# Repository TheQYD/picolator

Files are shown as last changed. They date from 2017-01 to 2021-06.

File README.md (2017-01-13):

## Picolator
A portable console for [Pico 8] (http://www.lexaloffle.com/pico-8.php).   

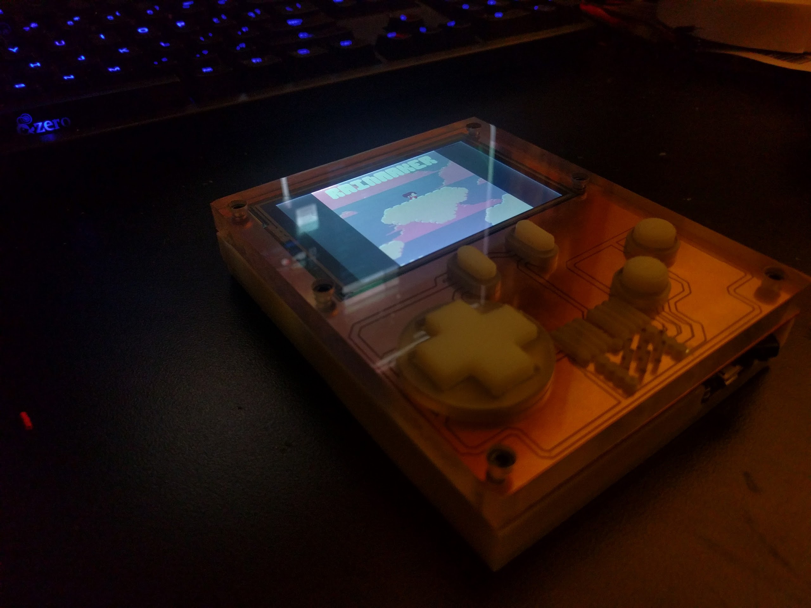
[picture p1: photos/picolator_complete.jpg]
(Picolator Complete Picolator


## Details
Picolator is a portable console developed using the Raspberry Pi Zero. It's shell and circuits are made using the [Othermill](https://othermachine.co). 

Anyone with experience in milling and circuit design should be able to make it from just the files. I'll put together an Instructable soon. Check the notes for design details.

## Parts
- 1 [Raspberry Zero] (https://www.adafruit.com/product/2885)
- 1 [Teensy 3.2] (https://www.pjrc.com/store/teensy32.html)
- 1 [Adafruit 3.5” PiTFT] (https://www.adafruit.com/products/2097)
- 1 [LM386 Audio Amplifier] (http://www.digikey.com/product-detail/en/texas-instruments/LM386N-4-NOPB/296-43960-5-ND/148192)
- 1 [Adafruit PowerBoost 500c] (https://www.adafruit.com/product/1944)
- 1 [3.7v 2500mAh LiPo battery] (https://www.adafruit.com/products/328)
- 1 [2.5mm headphone jack] (https://www.amazon.com/uxcell-Plastic-Stereo-Socket-Connector/dp/B00GLQAF7A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)
- 1 [sheet of 4” x 3” x .375” polycarbonate] (https://othermachine.co/store/materials/polycarbonate/)
- 2 [sheets of 4” x 3” x .375” HDPE] (https://othermachine.co/store/materials/hdpe/)
- 1 [sheet of 4” x 3” copper clad FR-1](https://othermachine.co/store/materials/pcb)
- Misc: resistors, capacitors, switch, etc.

## Media
A video it it in action can be found [here](https://youtu.be/5mOcTelc-4U).

The front.

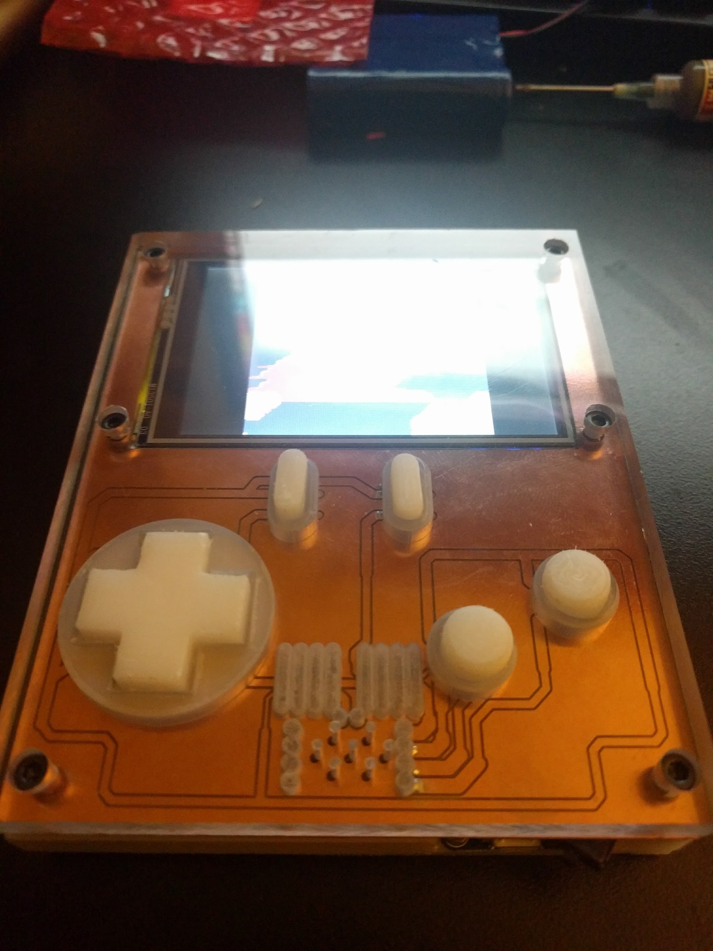
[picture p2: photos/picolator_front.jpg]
Front Picolator


The back.

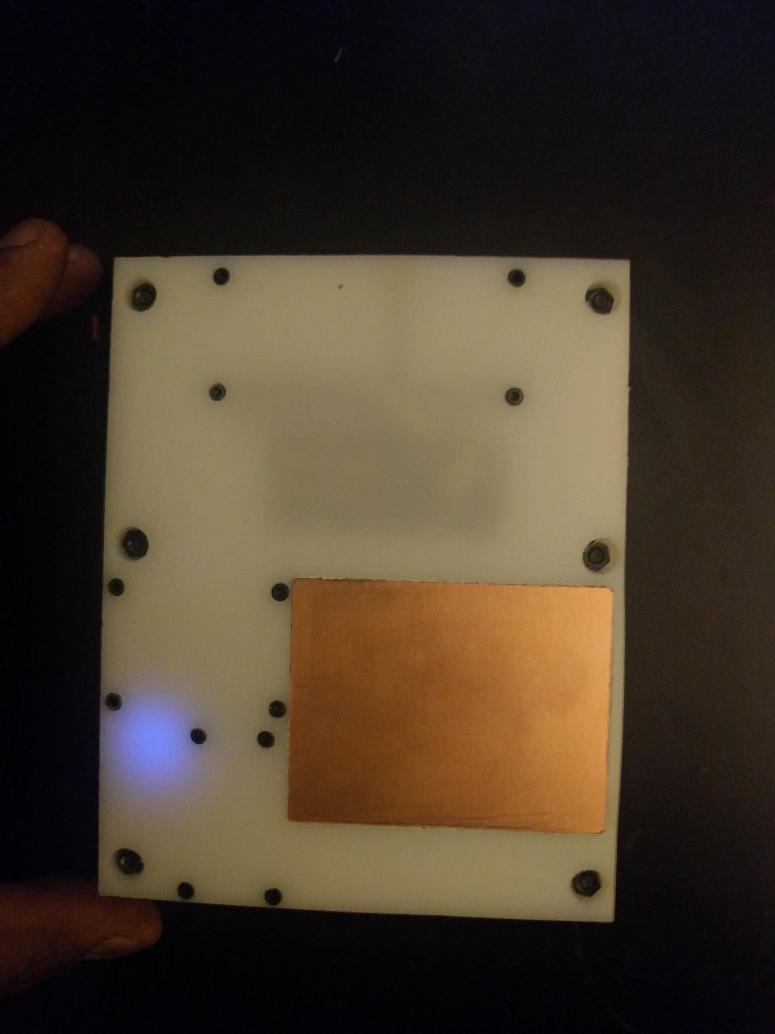
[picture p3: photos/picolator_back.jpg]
Back Picolator


I use it all the time.

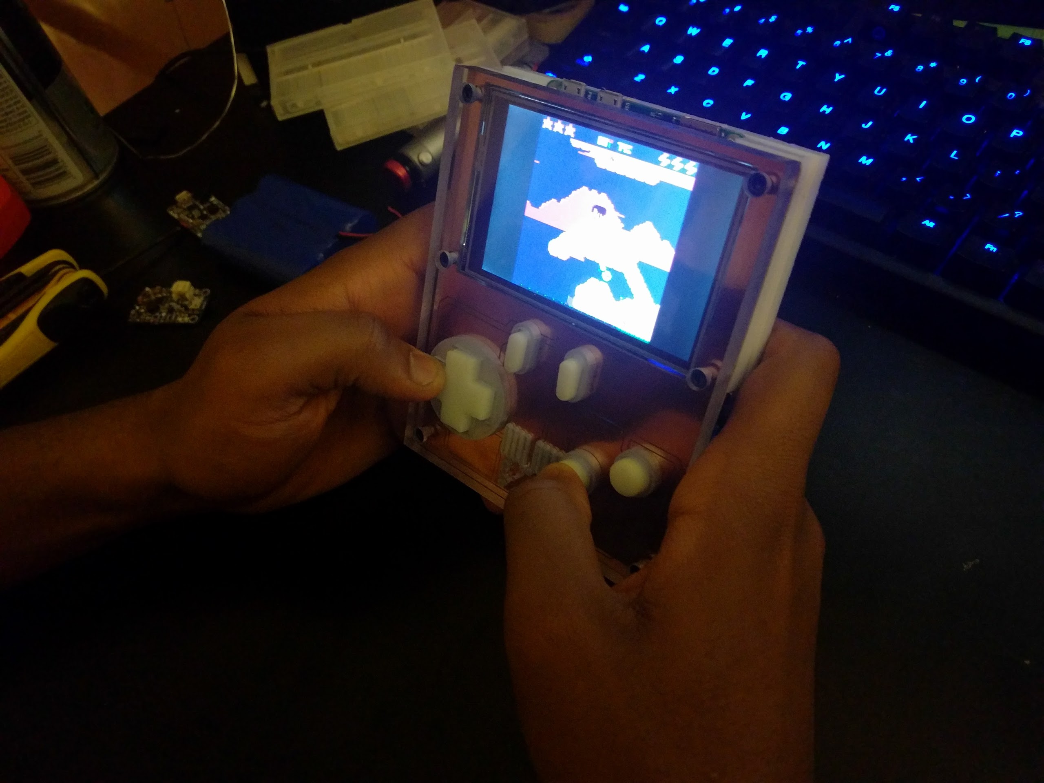
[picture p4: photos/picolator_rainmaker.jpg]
PLaying Picolator


Here are it's insides. I was breadboarding it.

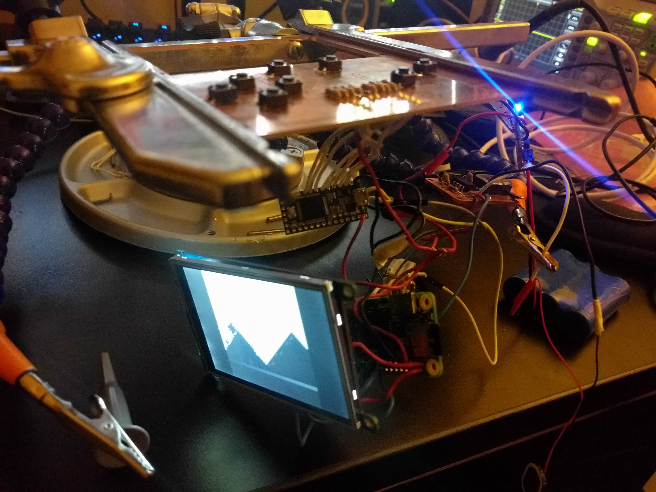
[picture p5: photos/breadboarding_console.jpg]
Breadboarding Picolator


This is the soundboard. It uses an LM386. I designed this circuit for the console, but the Pi Zero audio output instructions can be found [here](https://learn.adafruit.com/introducing-the-raspberry-pi-zero/audio-outputs). It's based on that.

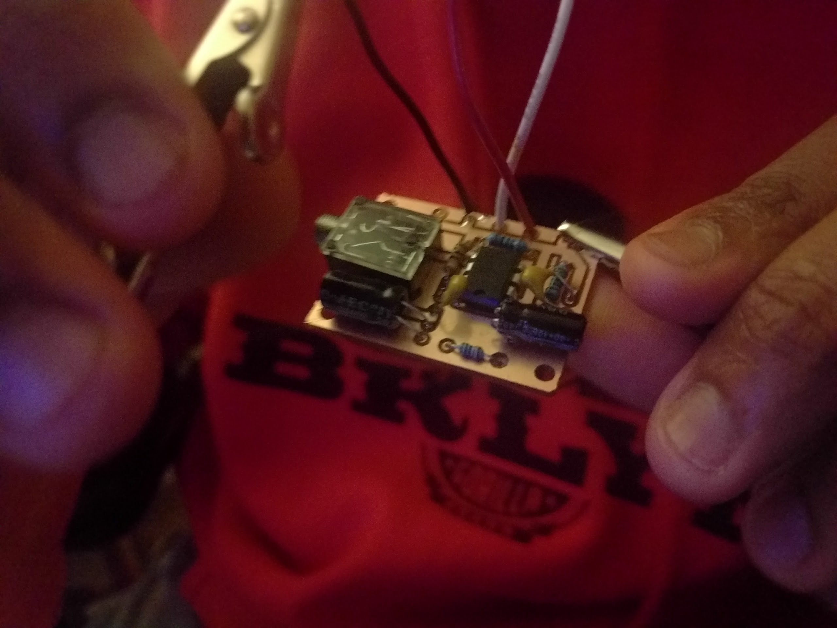
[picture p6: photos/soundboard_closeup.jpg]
Soundboard Picolator


The schematic for the soundboard is in the CADs folder, but here's an image of it.

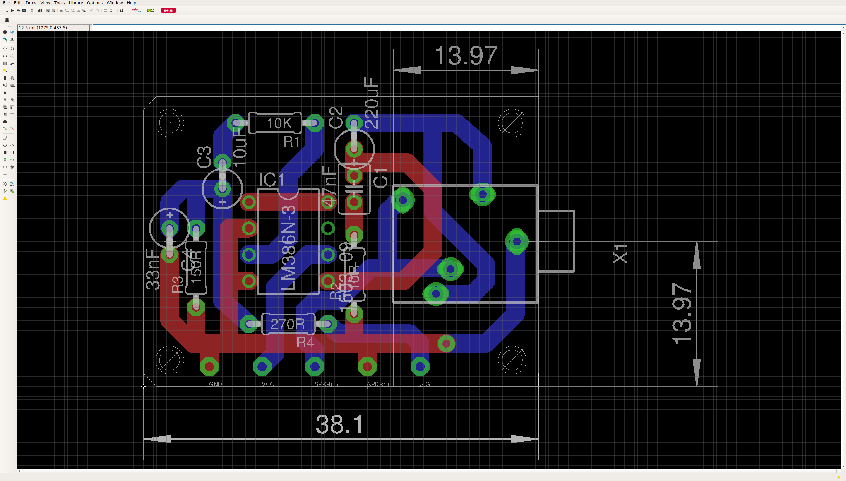
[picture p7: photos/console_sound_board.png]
You actually read these? Picolator


This is the controller. It connects to the Teensy and the Teensy is then connected via USB to the Pi Zero.

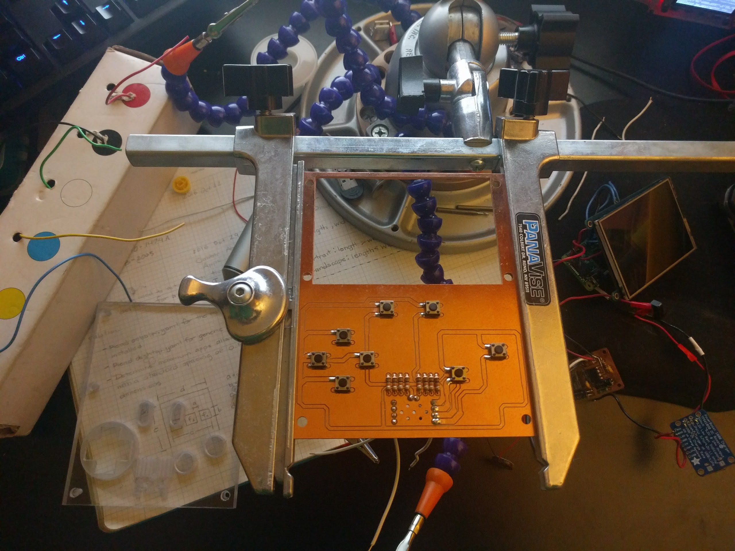
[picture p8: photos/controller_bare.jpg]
There is nothing here. Picolator


This is a screenshot of the controller circuit. It's also in the CADs folder.

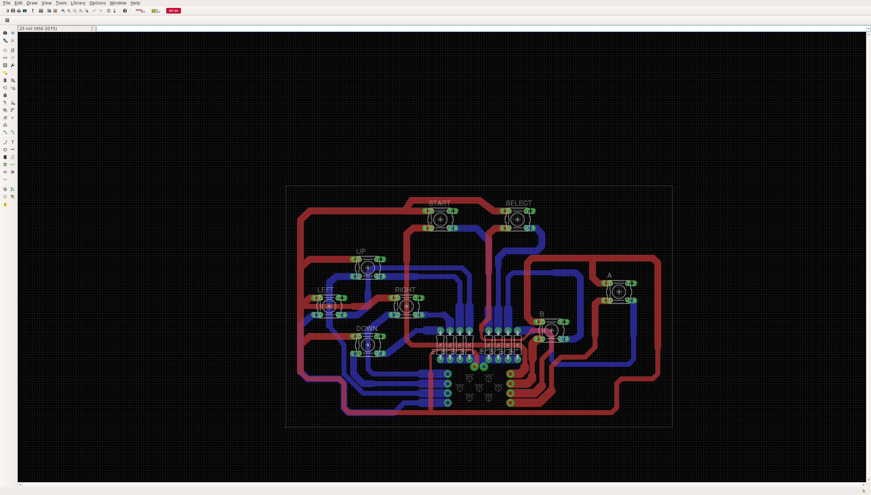
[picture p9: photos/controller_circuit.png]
This statement has no meaning. Picolator


## Notes
The shell is 4 layers. Three HDPE layers and a polycarbonate top layer (to protect the screen). The body was designed in Fusion 360, and the electronics were designed in EagleCAD. All of them were milled using the Othermill. I had to use a Dremel to remove the headers on the PiTFT (risky, but it needed to be thinner). It's not hollow, there are supports and channels to route the wires and mount equipment on the inside (see the CADs).

When I started, I found the PiTFT schematic and tested the pins used for video (SPI). The wires are 28 gauge stranded core. If you look through Google Images for any of those things you'd need, you'll find them. Lady Ada makes the schematics for the PiTFT available on her site. The mappings I found in Google images, and tested using an oscilliscope.

The joystick is milled in two parts. The section for the screen is located in the cads/body directory. The circuit is located in the body/circuits directory. The resistors are 10k pullups. The Teensy code has a mapping of the pins, which are also labeled on the schematic.

The image is Lady Ada's PiTFT image (Raspbian), so the SD Card is 8GB. I couldn't get it booting when I used dd on a 32GB card. If anyone knows why, send me message -- though I don't think that's necessary even if I had every Pico-8 game ever. The games are played in Pico-8. You can place the flags in rc.local so it starts automatically. Pico 8 is available from [Lexaloffle Games](http://www.lexaloffle.com/pico-8.php). All of the games are made by the community using Lua (I guess I'm about to learn Lua!). 

That's it for now, until I have time to write an Instructable.

## License
Picolator is available under the MIT license. See the LICENSE file for more info. Make it better!

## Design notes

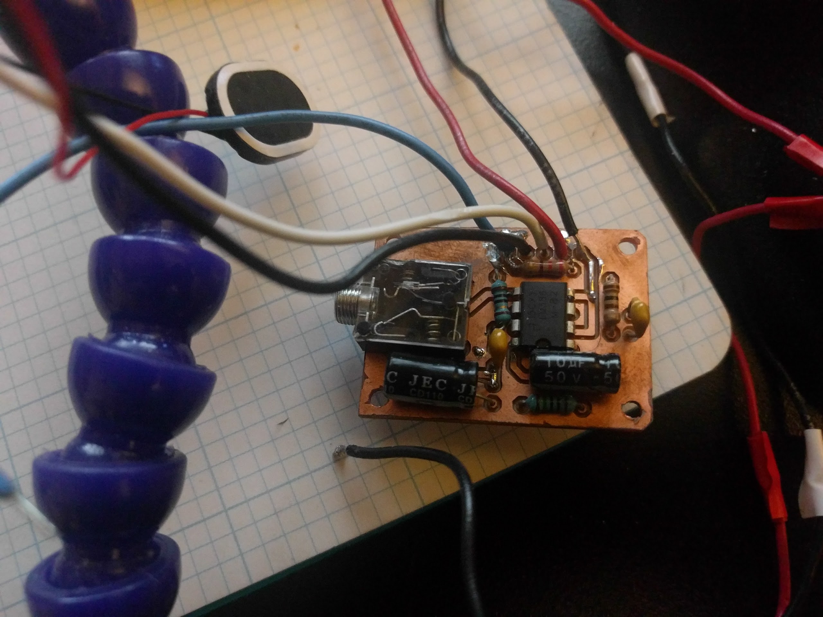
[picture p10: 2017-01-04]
photos/soundboard_bare.jpg

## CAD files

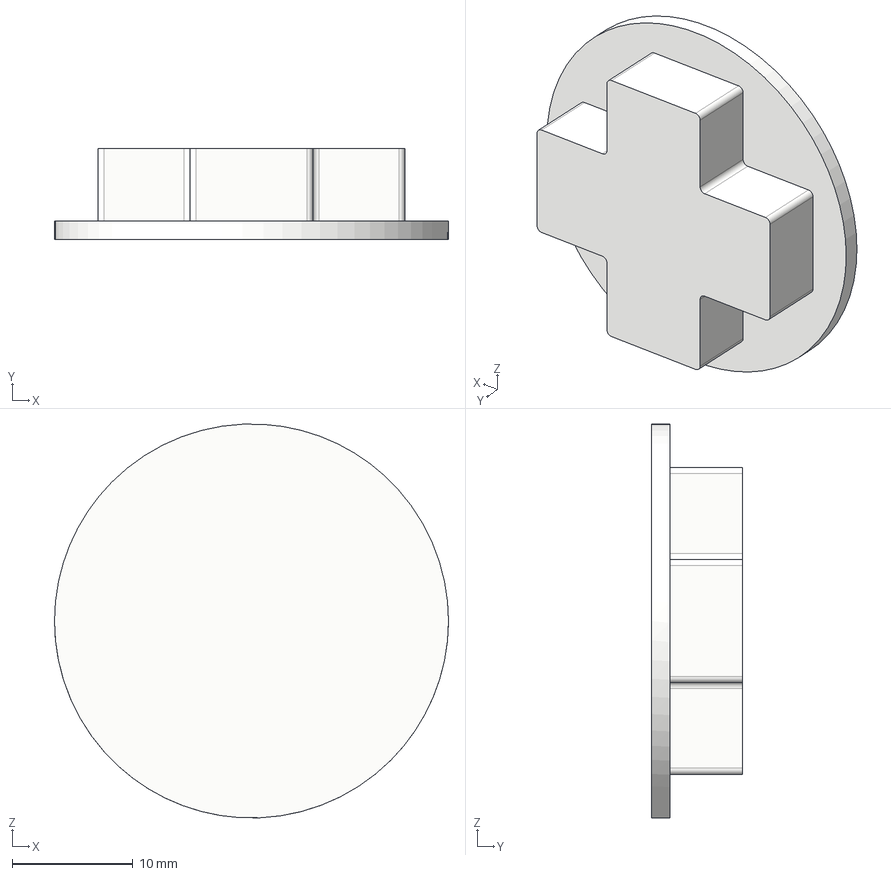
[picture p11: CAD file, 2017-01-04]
cads/body/D-Pad v8.iges
32.6 x 7.50 x 32.6 mm

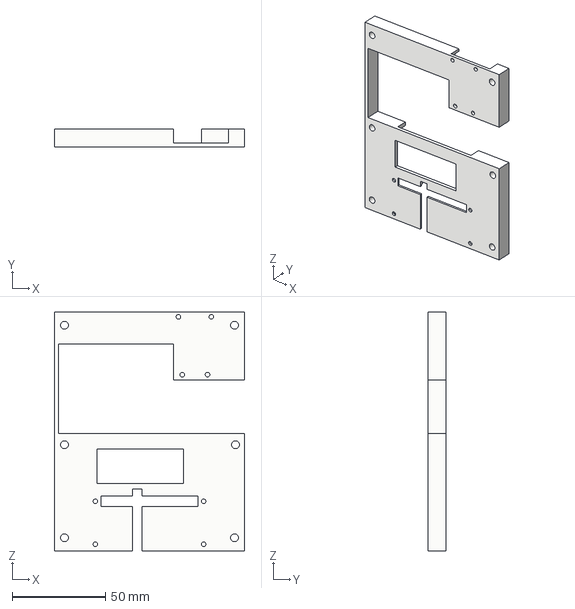
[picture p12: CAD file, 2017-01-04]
cads/body/Midframe.iges
102.0 x 9.50 x 128.2 mm

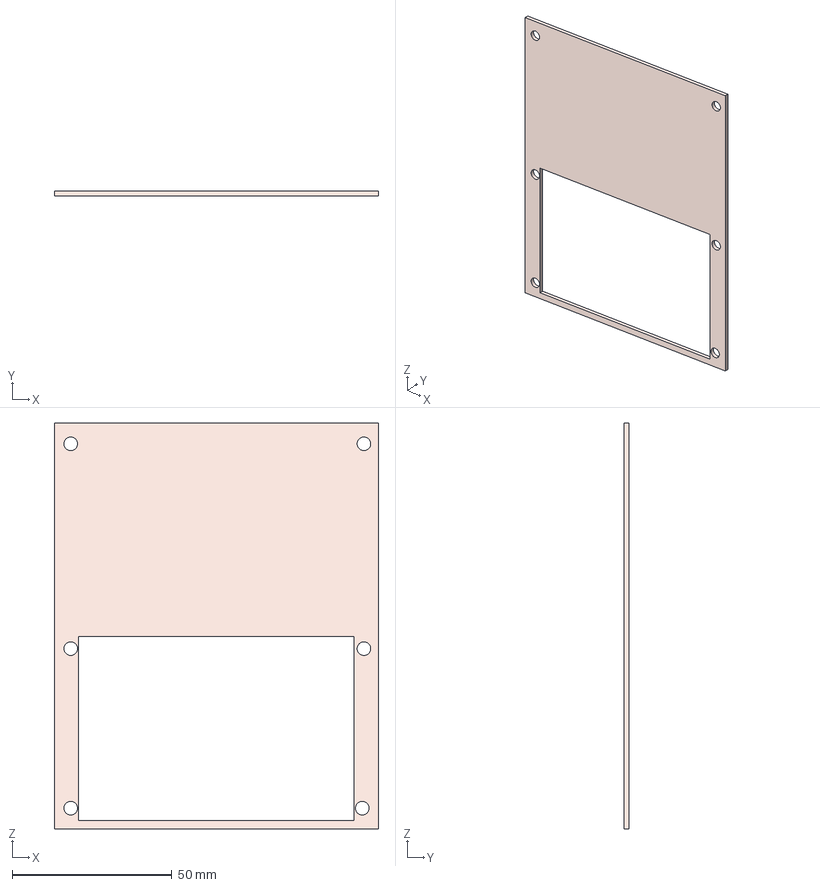
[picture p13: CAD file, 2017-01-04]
cads/body/Controller.iges
101.5 x 1.60 x 127.0 mm

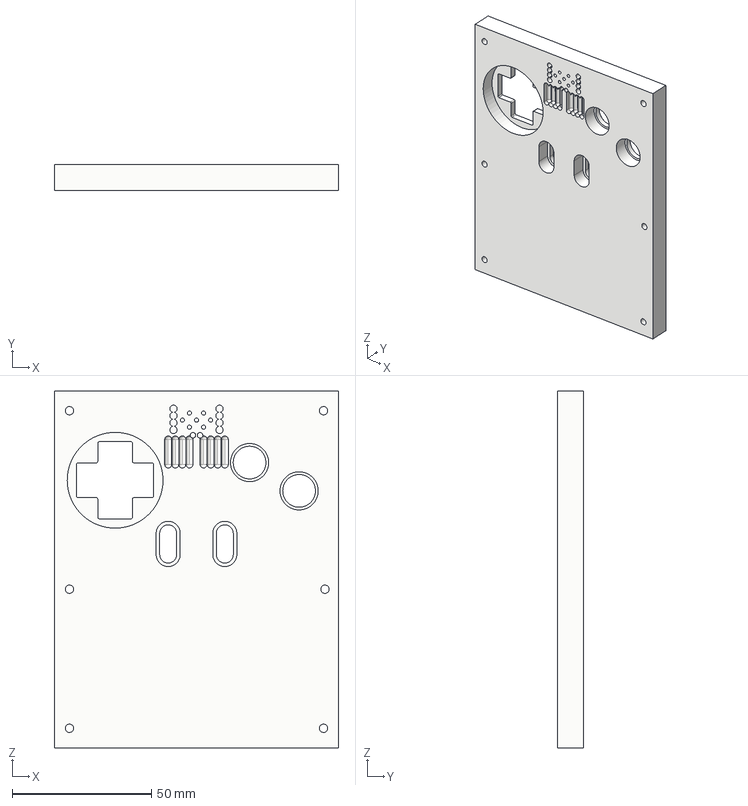
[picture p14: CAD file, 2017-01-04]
cads/body/Cover.iges
102.0 x 9.50 x 128.2 mm

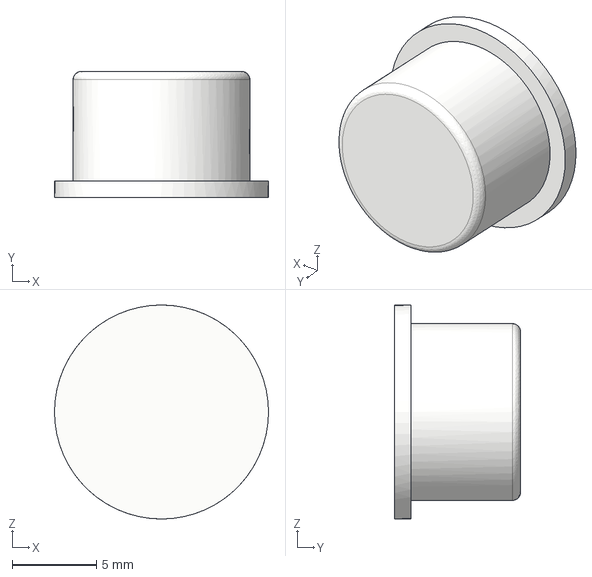
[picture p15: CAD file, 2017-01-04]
cads/body/Action Button.iges
12.7 x 7.50 x 12.7 mm

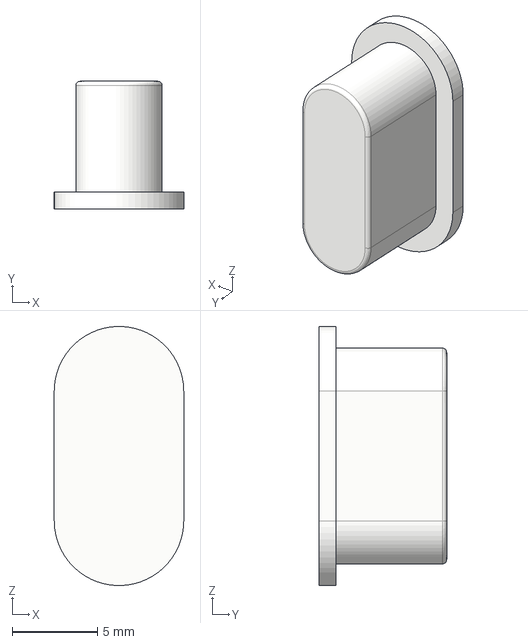
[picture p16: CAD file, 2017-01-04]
cads/body/Push Button.iges
7.62 x 7.50 x 15.2 mm

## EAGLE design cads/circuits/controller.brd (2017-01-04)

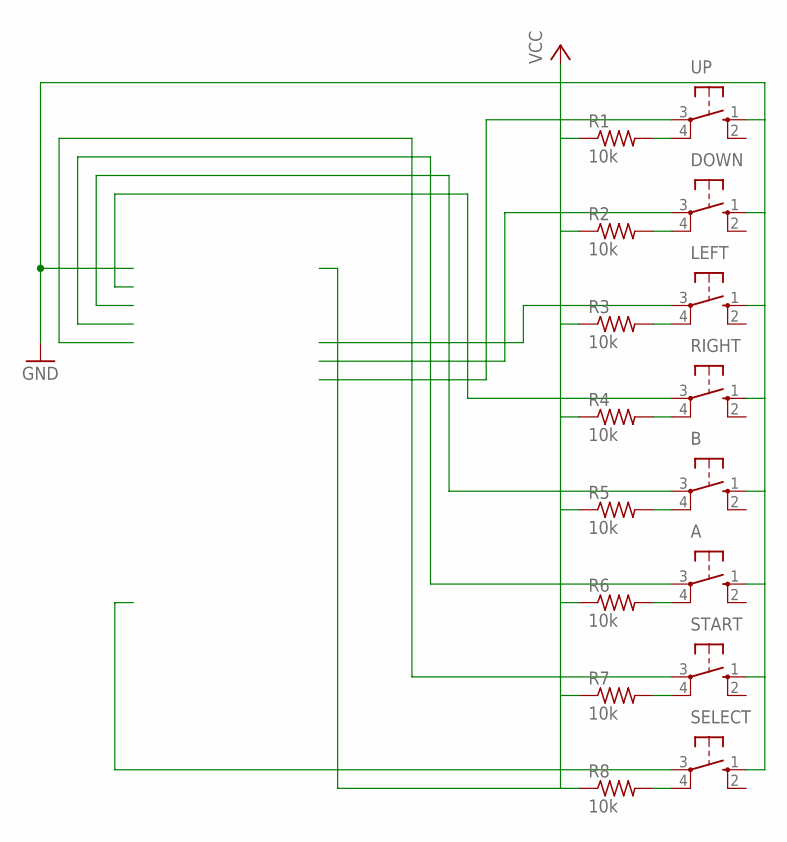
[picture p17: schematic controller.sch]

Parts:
A: 10-XX; B3F-10XX
B: 10-XX; B3F-10XX
DOWN: 10-XX; B3F-10XX
LEFT: 10-XX; B3F-10XX
R1, R2, R3, R4, R5, R6, R7, R8: 10k; 0204/7
RIGHT: 10-XX; B3F-10XX
SELECT: 10-XX; B3F-10XX
START: 10-XX; B3F-10XX
UP: 10-XX; B3F-10XX

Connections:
GND: A.1 (S), B.1 (S), DOWN.1 (S), LEFT.1 (S), RIGHT.1 (S), SELECT.1 (S), START.1 (S), UP.1 (S)
unnamed: DOWN.4 (P1), R2.2
unnamed: LEFT.4 (P1), R3.2
unnamed: R1.1, R2.1, R3.1, R4.1, R5.1, R6.1, R7.1, R8.1
unnamed: R7.2, START.4 (P1)
unnamed: R4.2, RIGHT.4 (P1)
unnamed: A.4 (P1), R6.2
unnamed: B.4 (P1), R5.2
unnamed: R8.2, SELECT.4 (P1)
unnamed: R1.2, UP.4 (P1)

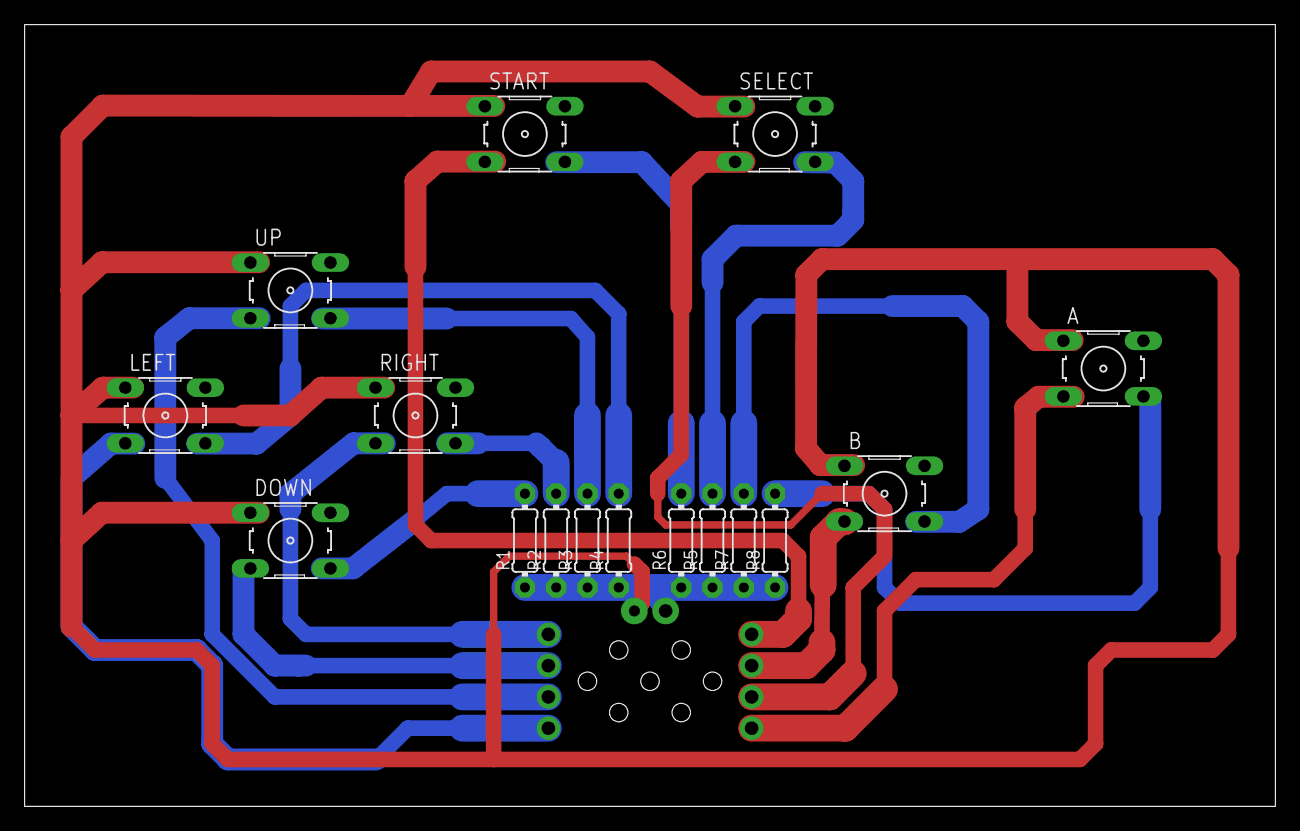
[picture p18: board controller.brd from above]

Board: 2 copper layers, 101.6 x 63.5 mm, 16 parts (0 on the bottom side), 10 nets.

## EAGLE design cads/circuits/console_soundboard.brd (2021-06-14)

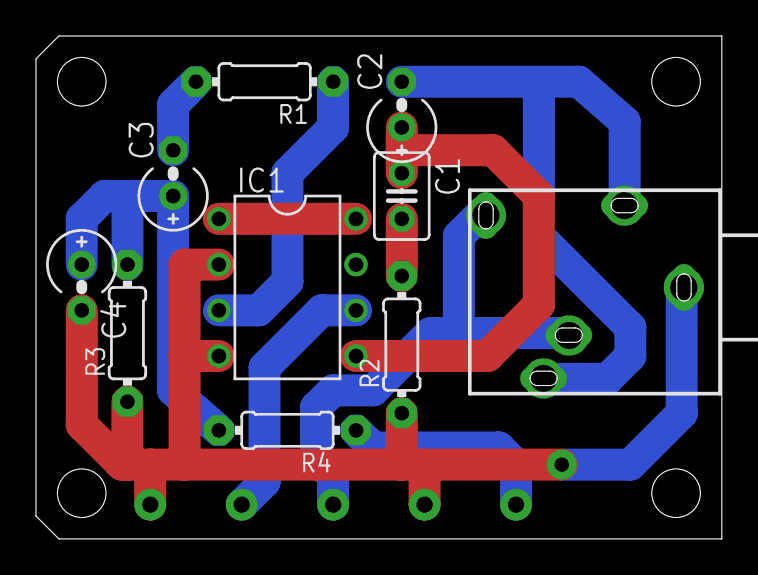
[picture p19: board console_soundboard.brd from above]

Board: 2 copper layers, 38.1 x 27.9 mm, 10 parts (0 on the bottom side), 9 nets.

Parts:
C1: 47nF; C025-030X050
C2: 220uF; E2,5RE
C3: 10uF; E2,5RE
C4: 33nF; E2,5RE
IC1: LM386N-3; DIL08
R1: 10K; 0204/7
R2: 10R; 0204/7
R3: 150R; 0204/7
R4: 270R; 0204/7
X1: 1503_09

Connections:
unnamed: IC1.3, R1.1
unnamed: C1.1, C2.+, IC1.5
unnamed: C1.2, R2.2
unnamed: C3.+, C4.+, R3.2, R4.2
unnamed: X1.4, X1.5
unnamed: IC1.1, IC1.8
unnamed: C4.-, IC1.2, IC1.4, R2.1, R3.1, X1.1
NN: C3.-, R1.2
OUT: C2.-, X1.2, X1.3

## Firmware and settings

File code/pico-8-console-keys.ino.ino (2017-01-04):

#include <Bounce.h>

Bounce button1 = Bounce(1, 10);
Bounce button2 = Bounce(2, 10);
Bounce button3 = Bounce(3, 10);
Bounce button4 = Bounce(4, 10);
Bounce button5 = Bounce(5, 10);
Bounce button6 = Bounce(6, 10);
Bounce button7 = Bounce(7, 10);
Bounce button8 = Bounce(8, 10);
Bounce button9 = Bounce(9, 10);

void setup() {
  pinMode(1, INPUT_PULLDOWN);
  pinMode(2, INPUT_PULLDOWN);
  pinMode(3, INPUT_PULLDOWN);
  pinMode(4, INPUT_PULLDOWN);
  pinMode(5, INPUT_PULLDOWN);
  pinMode(6, INPUT_PULLDOWN);
  pinMode(7, INPUT_PULLDOWN);
  pinMode(8, INPUT_PULLDOWN);
  pinMode(9, INPUT_PULLDOWN);
}

void loop() {
  button1.update();
  button2.update();
  button3.update();
  button4.update();
  button5.update();
  button6.update();
  button7.update();
  button8.update();
  button9.update();

  //release Button Code

  if (button1.fallingEdge()) {
    Keyboard.release(KEY_UP);
  }
  if (button2.fallingEdge()) {
    Keyboard.release(KEY_DOWN);
  }
  if (button3.fallingEdge()) {
    Keyboard.release(KEY_LEFT);
  }
  if (button4.fallingEdge()) {
    Keyboard.release(KEY_RIGHT);
  }
  if (button5.fallingEdge()) {
    Keyboard.release(KEY_Z);
  }
  if (button6.fallingEdge()) {
    Keyboard.release(KEY_X);
  }
  if (button7.fallingEdge()) {
    Keyboard.release(KEY_ESC);
  }
  if (button8.fallingEdge()) {
    Keyboard.release(KEY_ENTER);
  }

  //press Button Code

  if (button1.risingEdge()) {
    Keyboard.press(KEY_UP);
  }
  if (button2.risingEdge()) {
    Keyboard.press(KEY_DOWN);
  }
  if (button3.risingEdge()) {
    Keyboard.press(KEY_LEFT);
  }
  if (button4.risingEdge()) {
    Keyboard.press(KEY_RIGHT);
  }
  if (button5.risingEdge()) {
    Keyboard.press(KEY_Z);
  }
  if (button6.risingEdge()) {  
    Keyboard.press(KEY_X);
  }
  if (button7.risingEdge()) {
    Keyboard.press(KEY_ESC);
  }
  if (button8.risingEdge()) {
    Keyboard.press(KEY_ENTER);
  }
}

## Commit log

2017-01-04 fixing cads
    [Action Button.iges, Controller.iges, Cover.iges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]
2021-06-14 Added console soundboard.
    [console_soundboard.brd]
